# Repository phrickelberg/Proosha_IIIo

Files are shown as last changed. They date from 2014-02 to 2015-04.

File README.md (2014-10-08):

Proosha IIIo
=========================

This RepRap is available under GPL license.

This is basically a Prusa i3 Einstein Rework with minor changes such as:

* wood-style frame with fins upgraded to fit the Einstein Rework Y-CORNERS
* stronger X-END-IDLER
* stronger X-END-MOTOR
* preconfigured Marlin Firmware

Building instructions
-------------------------
Instead of the original threaded rod configuration, you need

* 2x Threaded rod M5x300 mm
* 2x Threaded rod M10x210 mm
* 2x Threaded rod M10x365 mm
* 2x Threaded rod M10x380 mm

and a few more M10 nuts and washers plus two M8 x 20 mm screws.

You also need to tap the printed X-END-IDLER-BETTER.stl twice with a M8 x 1,25 thread. Thats where the two M8 x 20 mm screws go.

Besides that, just follow the instructions from [the original project page](http://reprap.org/wiki/Prusa_i3_Rework_Introduction/de)

If you want to use the preconfigured Marlin Firmware, please make sure you got your hardware configured as followed:
* explanation:				{X-AXIS, Y-AXIS, Z-AXIS, EXTRUDER}
* microstepping:			{1/8, 1/8, 1/4, 1/4}
* motors step angle:	{1.8, 1.8, 1.8, 1.8}
* transmission:				{20 teeth GT2, 20 teeth GT2, M5 thread (0.8 mm/rev), hardened steel hobbed bolt + wade gear}

Roadmap
-------------------------

- [x] modifying the x-end idler to more solid, right now the ball-bearing mount it's a predetermined breaking point
- [x] modifying the wood frame fins to fit the i3 EINSTEIN Rework y-corners and 10mm threaded rods
- [ ] modifying the y-carrier for 3-point leveling AND for triggering the lower y-endstop even if the bed is mounted a few mm higher (i.e. due to leveling screws)

Sources
-------------------------

* Prusa i3 EINSTEIN Rework Introduction [github.com](http://reprap.org/wiki/Prusa_i3_Rework_Introduction)
* Extruder-Classic parts by ch1t0 [Thingiverse](http://www.thingiverse.com/thing:76660)
* Extruder-E3D parts by Mak-a-face [Thingiverse](http://www.thingiverse.com/thing:76660)
* Extruder parts by ch1t0 [Thingiverse](http://www.thingiverse.com/thing:76660)
* Marlin Firmware [GitHub](https://github.com/ErikZalm/Marlin)

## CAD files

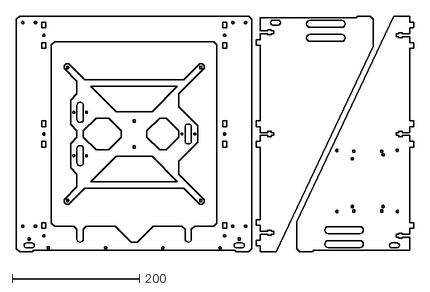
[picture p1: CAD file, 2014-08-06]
Frame/Prusa3WOOD-v4-Einstein-Rework-Retrofit-Laser-Closed-Radius-140722.dxf
623.9 x 370.0

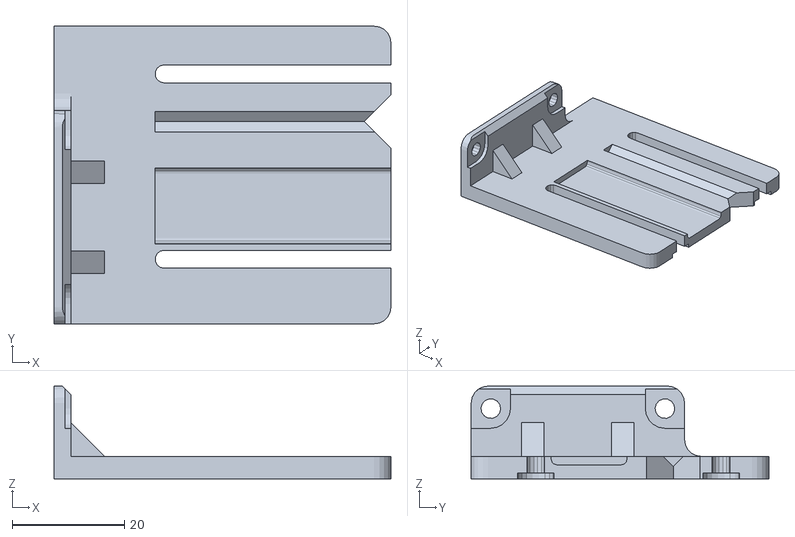
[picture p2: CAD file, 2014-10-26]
STL parts/ENSTOP-Z-HOLDER/ENDSTOP-Z-HOLDER-LONGER.stl
60.0 x 53.0 x 16.5

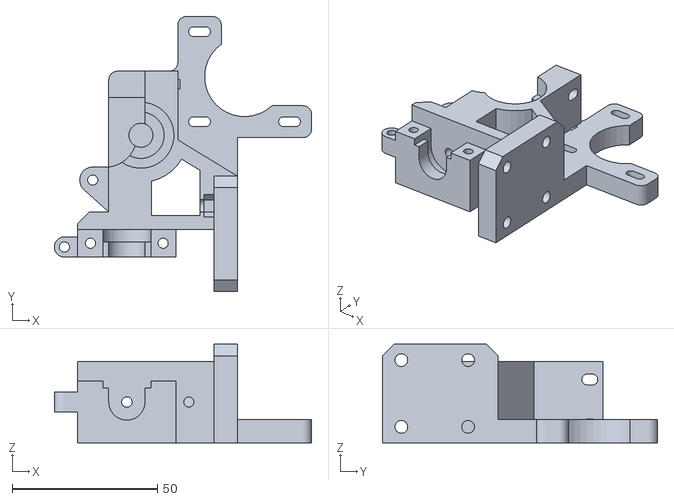
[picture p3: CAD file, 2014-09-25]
STL parts/EXTRUDEUR/BODY-EXTRUDER-WADE-E3D/i3R_E3D_Extruder_01.STL
88.7 x 94.7 x 34.0

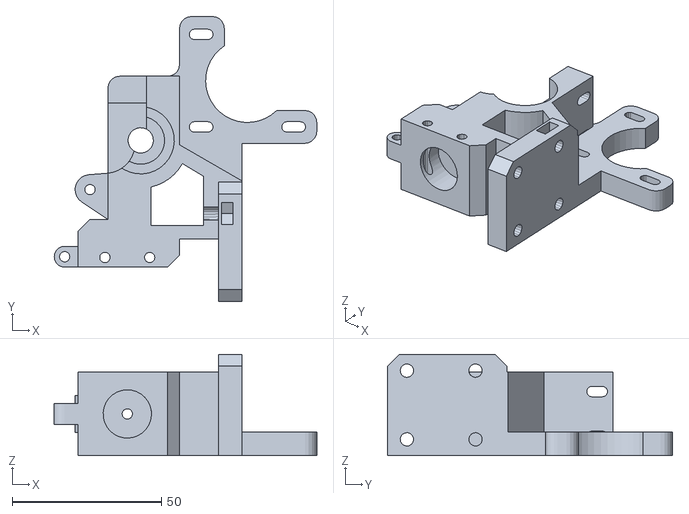
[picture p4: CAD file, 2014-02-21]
STL parts/EXTRUDEUR/BODY-EXTRUDEUR-WADE-CLASSIC/BODY-EXTRUDEUR-WADE.stl
88.0 x 95.5 x 34.0

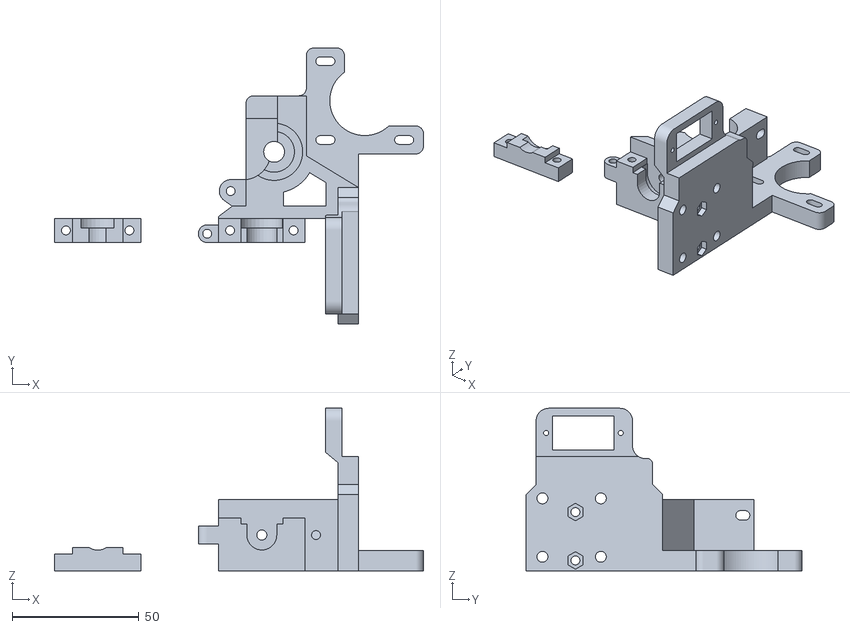
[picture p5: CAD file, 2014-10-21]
STL parts/EXTRUDEUR/BODY-EXTRUDEUR-WADE-E3D-AB/e3dv6_with_clip.stl
145.3 x 108.7 x 64.0

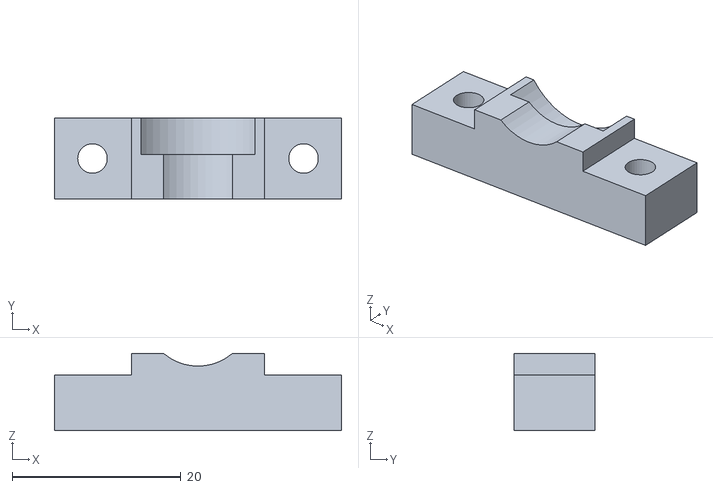
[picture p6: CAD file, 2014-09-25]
STL parts/EXTRUDEUR/BODY-EXTRUDEUR-WADE-E3D/i3R_E3D_Mounting_Clamp_01.STL
34.0 x 9.58 x 9.12

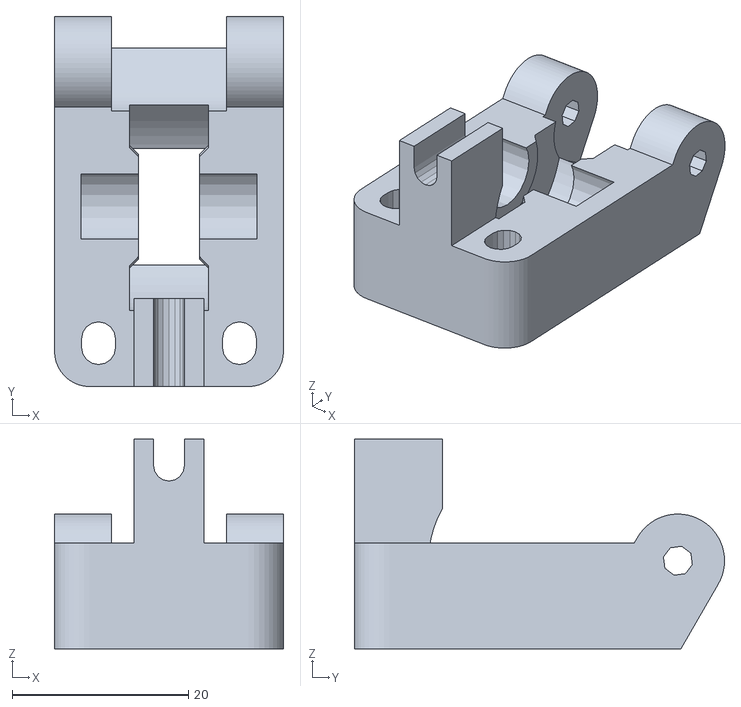
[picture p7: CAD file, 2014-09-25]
STL parts/EXTRUDEUR/EXTRUDER-IDLER/EXTRUDER-IDLER-avec-guide.stl
26.0 x 42.0 x 23.8

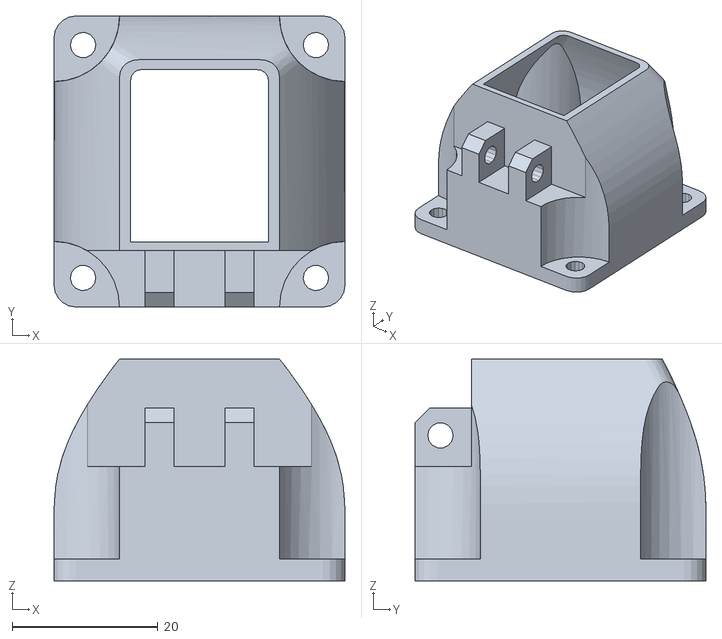
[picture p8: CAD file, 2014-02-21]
STL parts/EXTRUDEUR/FAN-DUCT/FAN-DUCT.stl
40.0 x 40.0 x 30.5

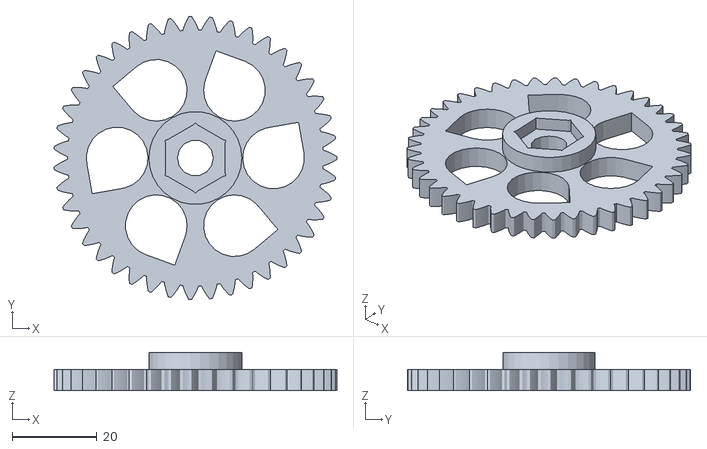
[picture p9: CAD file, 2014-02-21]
STL parts/EXTRUDEUR/WADE-BIG-GEAR/WADE-BIG-GEAR.stl
66.9 x 67.0 x 9.00

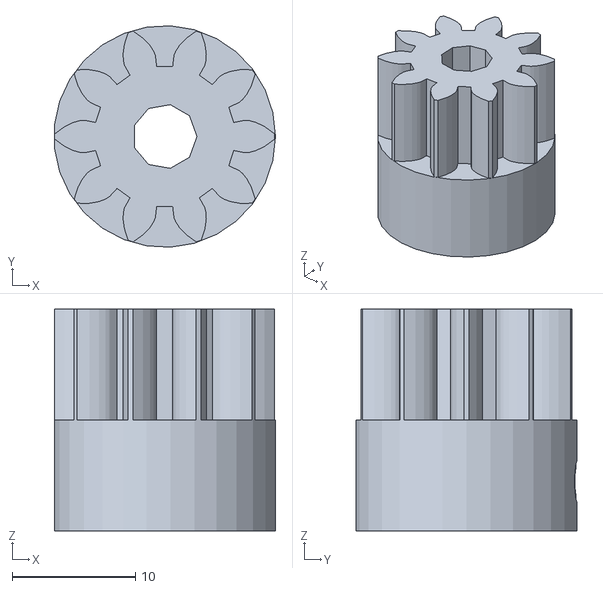
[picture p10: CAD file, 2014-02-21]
STL parts/EXTRUDEUR/WADE-SMALL-GEAR/WADE-SMALL-GEAR.stl
17.9 x 18.0 x 18.0

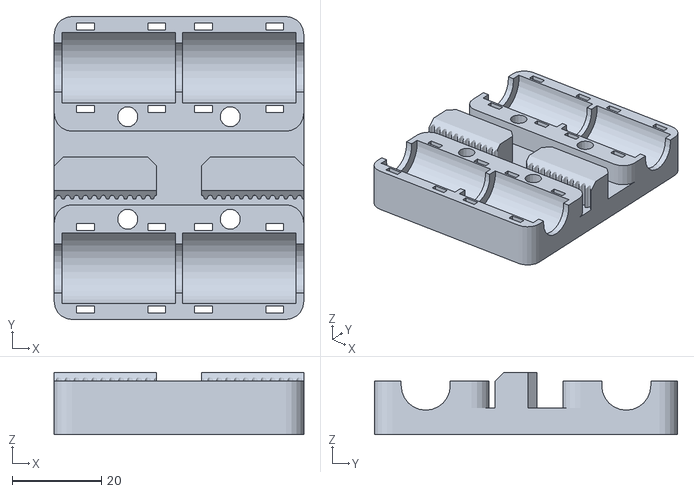
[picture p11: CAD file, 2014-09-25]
STL parts/X-CARRIAGE/X-CARRIAGE-IGUS.stl
56.0 x 68.0 x 14.0

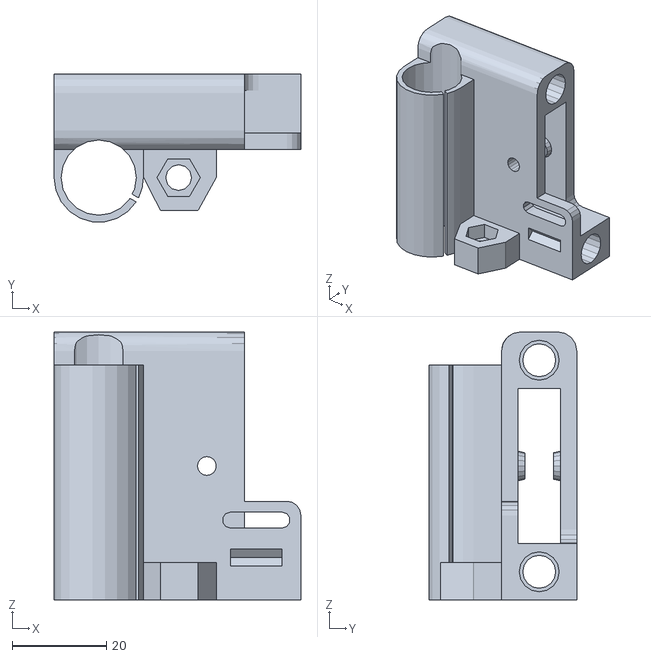
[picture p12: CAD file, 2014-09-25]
STL parts/X-END-IDLER/X-END-IDLER-BETTER-IGUS.stl
52.5 x 31.4 x 57.0

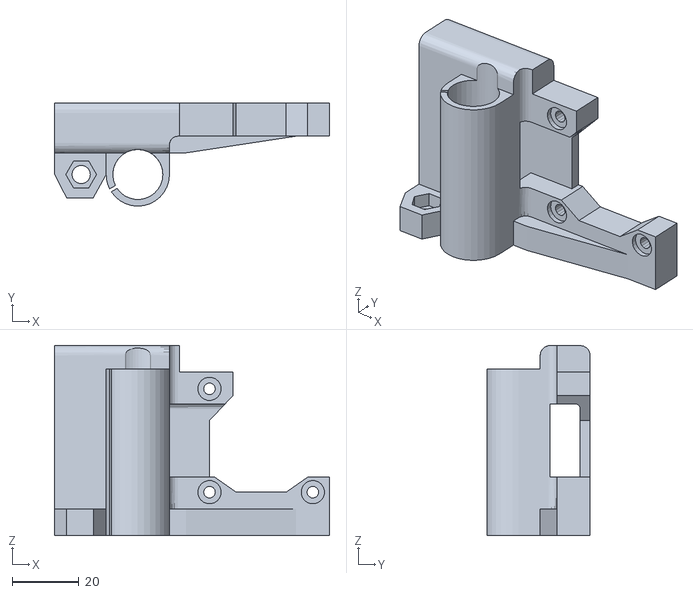
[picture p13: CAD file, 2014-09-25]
STL parts/X-END-MOTOR/X-END-MOTOR-V2.stl
82.5 x 31.0 x 57.0

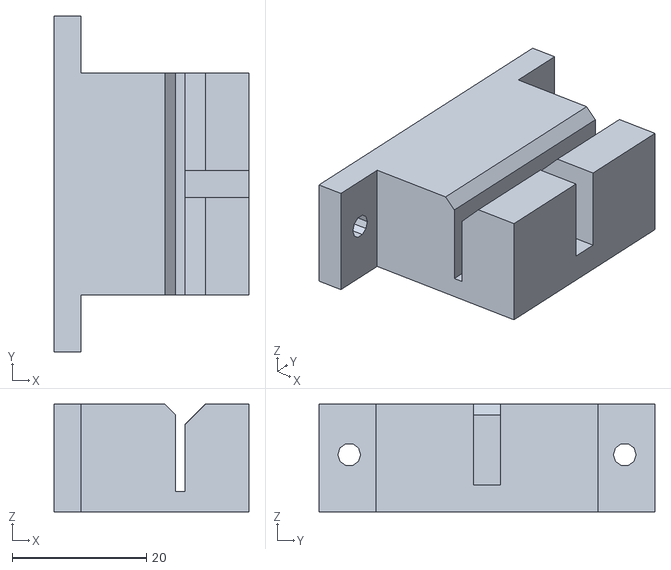
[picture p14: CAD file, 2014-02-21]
STL parts/Y-BELT-HOLDER/Y-BELT-HOLDER.stl
29.0 x 50.0 x 16.0

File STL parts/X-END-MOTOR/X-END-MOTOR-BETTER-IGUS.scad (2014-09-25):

module vanilla_motor(){
	import("X-END-MOTOR.stl");
}

motor_center=[44.75,2.5,0];
cutout_offset=8;

module better_motor(){
	difference(){
		union(){
			vanilla_motor();
			patch();
		}
		cutout();
	}
}

module patch(){
	union(){
		intersection(){
			translate([31.75,6,0])
				cube([10,3,32],center=true);
			translate([44.75,6,0])
				rotate([90,0,0])
					cylinder(r=20,h=3,center=true);
		}
		intersection(){
			union(){
				translate([34.5,2.5,13.25])
					cube([4.5,10,4.5],center=true);
				//translate([34.5,2.5,-13.25])
					//cube([4.5,10,4.5],center=true);
				translate([44.75,2.5,-15.5])
					cube([25,10,9],center=true);
		
			}
			translate([44.75,2.5,0])
				rotate([90,0,0])
					cylinder(r=18,h=10,center=true);
		}
	}
}

module cutout(){
	union(){
		translate([motor_center[0]-cutout_offset,2.5,motor_center[2]+cutout_offset])
			rotate([90,0,0])
				cylinder(r=6.5,h=11,center=true,$fn=36);
		translate([motor_center[0]-cutout_offset,2.5,motor_center[2]-cutout_offset])
			rotate([90,0,0])
				cylinder(r=6.5,h=11,center=true,$fn=36);
		translate([motor_center[0]+cutout_offset,2.5,motor_center[2]-cutout_offset])
			rotate([90,0,0])
				cylinder(r=6.5,h=11,center=true,$fn=36);
		translate([motor_center[0]-cutout_offset,2.5,0])
			cube([13,11,2*cutout_offset],center=true);
		translate([motor_center[0],2.5,motor_center[2]-cutout_offset])
			cube([2*cutout_offset,11,13],center=true);
		translate([motor_center[0]-cutout_offset,2.5,motor_center[2]+cutout_offset])
			rotate([90,0,0])
				cylinder(r=6.5,h=11,center=true,$fn=36);
		intersection(){
			translate([motor_center[0]-cutout_offset,2.5,motor_center[2]+cutout_offset])
				rotate([0,45,0])
					translate([0,0,6.5])
						cube([13,11,13],center=true,$fn=36);
			translate([motor_center[0]-cutout_offset,2.5,motor_center[2]+cutout_offset])
				rotate([0,45,0])
					cube([13,11,26],center=true,$fn=36);
			translate([motor_center[0]-cutout_offset,2.5,motor_center[2]+cutout_offset])
				cube([13,11,26],center=true,$fn=36);
		}
	}
}

module igus_motor(){
	difference(){
		better_motor();
		translate([7.75,-14,0])
			cylinder(r=16/2, h=60, center=true, $fn=20);
	}
}


igus_motor();

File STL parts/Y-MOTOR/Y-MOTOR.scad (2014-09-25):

projection(cut=true)
	translate([-50,0,-8])
		import("/Users/Moritz/Downloads/Proosha_IIIo-master/STL parts/Y-MOTOR/Y-MOTOR.stl");

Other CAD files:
STL parts/Y-CORNERS/experimental/Y-CORNERS.dxf
STL parts/Y-CORNERS/Y-CORNERS-HOLLOW.stl
STL parts/Y-IDLER/Y-IDLER.stl
STL parts/Y-MOTOR/Y-MOTOR.stl
STL parts/X-END-MOTOR/X-END-MOTOR-BETTER.scad
STL parts/X-END-MOTOR/X-END-MOTOR-IGUS.scad
Frame/Proosha_IIIo-Frame-v1.dxf
STL parts/ENSTOP-Z-HOLDER/ENDSTOP-Z-HOLDER-LONGER.scad
STL parts/ENSTOP-Z-HOLDER/ENDSTOP-Z-HOLDER.stl
STL parts/EXTRUDEUR/BODY-EXTRUDEUR-WADE-CLASSIC/BODY-EXTRUDEUR-WADE.scad
STL parts/EXTRUDEUR/BODY-EXTRUDEUR-WADE-E3D-AB/e3d_extru_alnoa_1.75_ab-only-clip.scad
STL parts/EXTRUDEUR/BODY-EXTRUDEUR-WADE-E3D-AB/e3d_extru_alnoa_1.75_ab-only-clip.stl
STL parts/EXTRUDEUR/BODY-EXTRUDEUR-WADE-E3D-AB/e3d_extru_alnoa_1.75_ab-without-clip.scad
STL parts/EXTRUDEUR/BODY-EXTRUDEUR-WADE-E3D-AB/e3d_extru_alnoa_1.75_ab-without-clip.stl
STL parts/EXTRUDEUR/BODY-EXTRUDEUR-WADE-E3D-AB/e3d_extru_alnoa_1.75_ab.STL
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

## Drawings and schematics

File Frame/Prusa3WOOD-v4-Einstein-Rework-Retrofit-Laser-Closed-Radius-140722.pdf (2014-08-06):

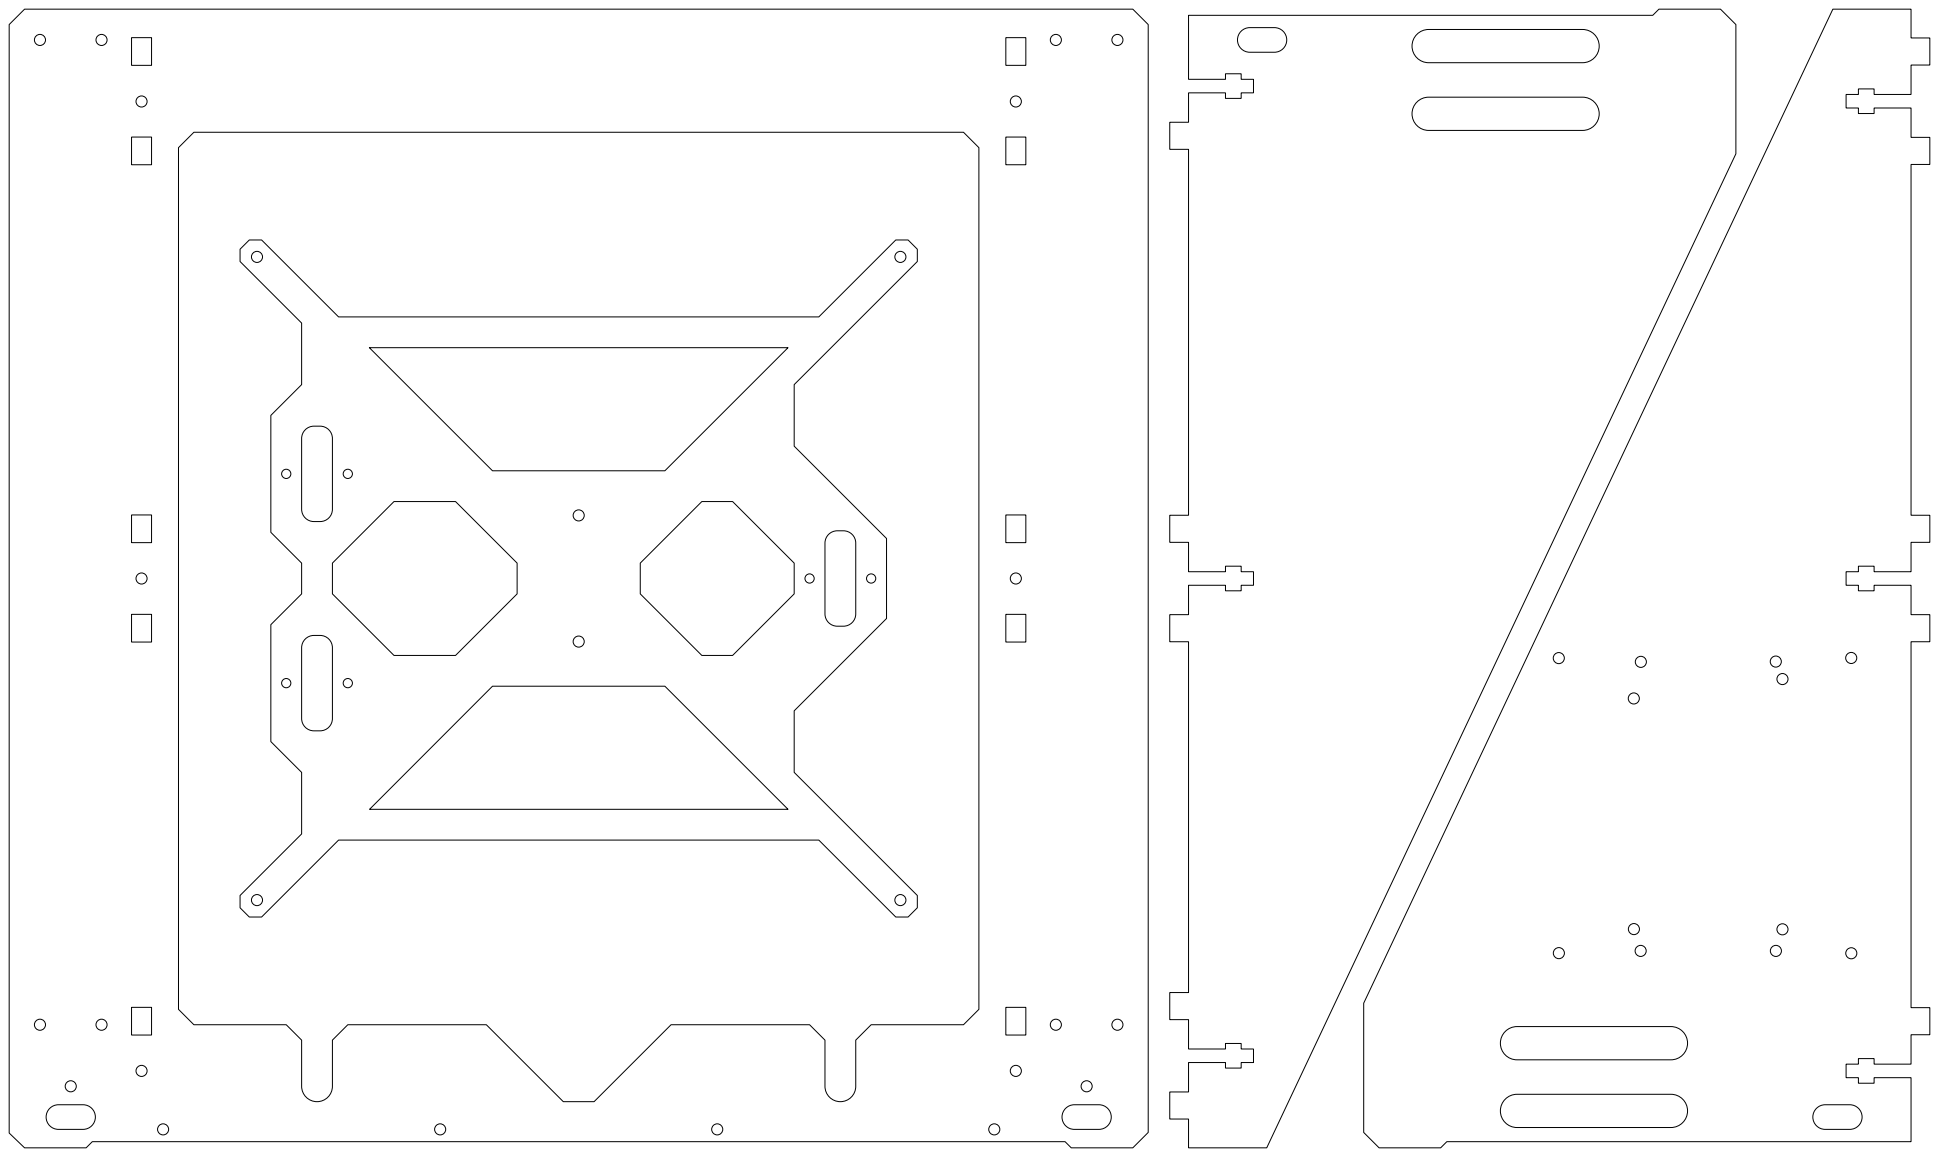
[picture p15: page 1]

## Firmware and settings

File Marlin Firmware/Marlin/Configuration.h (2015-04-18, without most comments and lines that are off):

#define CONFIGURATION_H
#define STRING_VERSION_CONFIG_H __DATE__ " " __TIME__ // build date and time
#define STRING_CONFIG_H_AUTHOR "(none, default config)" // Who made the changes.
#define SERIAL_PORT 0
#define BAUDRATE 250000
#define MOTHERBOARD 33
#define CUSTOM_MENDEL_NAME "> Totti <"
#define EXTRUDERS 1
#define POWER_SUPPLY 1
#define TEMP_SENSOR_0 5
#define TEMP_SENSOR_1 0
#define TEMP_SENSOR_2 0
#define TEMP_SENSOR_BED 5
#define MAX_REDUNDANT_TEMP_SENSOR_DIFF 10
#define TEMP_RESIDENCY_TIME 5  // (seconds)
#define TEMP_HYSTERESIS 2       // (degC) range of +/- temperatures considered "close" to the target one
#define TEMP_WINDOW     1       // (degC) Window around target to start the residency timer x degC early.
#define HEATER_0_MINTEMP 5
#define HEATER_1_MINTEMP 5
#define HEATER_2_MINTEMP 5
#define BED_MINTEMP 5
#define HEATER_0_MAXTEMP 315
#define HEATER_1_MAXTEMP 315
#define HEATER_2_MAXTEMP 315
#define BED_MAXTEMP 165
#define PIDTEMP
#define BANG_MAX 255 // limits current to nozzle while in bang-bang mode; 255=full current
#define PID_MAX 255 // limits current to nozzle while PID is active (see PID_FUNCTIONAL_RANGE below); 255=full current
  #define PID_FUNCTIONAL_RANGE 10 // If the temperature difference between the target temperature and the actual temperature
  #define PID_INTEGRAL_DRIVE_MAX 255  //limit for the integral term
  #define K1 0.95 //smoothing factor within the PID
  #define PID_dT ((OVERSAMPLENR * 8.0)/(F_CPU / 64.0 / 256.0)) //sampling period of the temperature routine
#define  DEFAULT_Kp 53.50
#define  DEFAULT_Ki 9.38
#define  DEFAULT_Kd 76.26
#define PIDTEMPBED
#define MAX_BED_POWER 255 // limits duty cycle to bed; 255=full current
    #define  DEFAULT_bedKp 46.34
    #define  DEFAULT_bedKi 4.23
    #define  DEFAULT_bedKd 126.8
#define PREVENT_DANGEROUS_EXTRUDE
#define PREVENT_LENGTHY_EXTRUDE
#define EXTRUDE_MINTEMP 170
#define EXTRUDE_MAXLENGTH (X_MAX_LENGTH+Y_MAX_LENGTH) //prevent extrusion of very large distances.
#define THERMAL_RUNAWAY_PROTECTION_PERIOD 40 //in seconds
#define THERMAL_RUNAWAY_PROTECTION_HYSTERESIS 4 // in degree Celsius
#define THERMAL_RUNAWAY_PROTECTION_BED_PERIOD 20 //in seconds
#define THERMAL_RUNAWAY_PROTECTION_BED_HYSTERESIS 4 // in degree Celsius
const bool X_MIN_ENDSTOP_INVERTING = true; // set to true to invert the logic of the endstop.
const bool Y_MIN_ENDSTOP_INVERTING = true; // set to true to invert the logic of the endstop.
const bool Z_MIN_ENDSTOP_INVERTING = true; // set to true to invert the logic of the endstop.
const bool X_MAX_ENDSTOP_INVERTING = true; // set to true to invert the logic of the endstop.
const bool Y_MAX_ENDSTOP_INVERTING = true; // set to true to invert the logic of the endstop.
const bool Z_MAX_ENDSTOP_INVERTING = true; // set to true to invert the logic of the endstop.
#if defined(COREXY) && !defined(DISABLE_MAX_ENDSTOPS)
  #define DISABLE_MAX_ENDSTOPS
#endif
#define X_ENABLE_ON 0
#define Y_ENABLE_ON 0
#define Z_ENABLE_ON 0
#define E_ENABLE_ON 0 // For all extruders
#define DISABLE_X false
#define DISABLE_Y false
#define DISABLE_Z false
#define DISABLE_E false // For all extruders
#define DISABLE_INACTIVE_EXTRUDER true //disable only inactive extruders and keep active extruder enabled
#define INVERT_X_DIR false    // for Mendel set to false, for Orca set to true
#define INVERT_Y_DIR true    // for Mendel set to true, for Orca set to false
#define INVERT_Z_DIR false     // for Mendel set to false, for Orca set to true
#define INVERT_E0_DIR true   // for direct drive extruder v9 set to true, for geared extruder set to false
#define INVERT_E1_DIR false    // for direct drive extruder v9 set to true, for geared extruder set to false
#define INVERT_E2_DIR false   // for direct drive extruder v9 set to true, for geared extruder set to false
#define X_HOME_DIR 1
#define Y_HOME_DIR -1
#define Z_HOME_DIR -1
#define min_software_endstops true // If true, axis won't move to coordinates less than HOME_POS.
#define max_software_endstops true  // If true, axis won't move to coordinates greater than the defined lengths below.
#define X_MAX_POS 200
#define X_MIN_POS 0
#define Y_MAX_POS 170
#define Y_MIN_POS 0
#define Z_MAX_POS 180
#define Z_MIN_POS 0
#define X_MAX_LENGTH (X_MAX_POS - X_MIN_POS)
#define Y_MAX_LENGTH (Y_MAX_POS - Y_MIN_POS)
#define Z_MAX_LENGTH (Z_MAX_POS - Z_MIN_POS)
#define Z_PROBE_REPEATABILITY_TEST  // If not commented out, Z-Probe Repeatability test will be included if Auto Bed Leveling is Enabled.
#define MANUAL_X_HOME_POS 200
#define MANUAL_Y_HOME_POS 0
#define MANUAL_Z_HOME_POS 0
#define NUM_AXIS 4 // The axis order in all axis related arrays is X, Y, Z, E
#define HOMING_FEEDRATE {50*60, 50*60, 3*60, 0}  // set the homing speeds (mm/min)
#define DEFAULT_AXIS_STEPS_PER_UNIT   {100,100,4000,680}
#define DEFAULT_MAX_FEEDRATE          {500, 500, 3, 25}    // (mm/sec)
#define DEFAULT_MAX_ACCELERATION      {9000,9000,100,10000}    // X, Y, Z, E maximum start speed for accelerated moves. E default values are good for Skeinforge 40+, for older versions raise them a lot.
#define DEFAULT_ACCELERATION          2000    // X, Y, Z and E max acceleration in mm/s^2 for printing moves
#define DEFAULT_RETRACT_ACCELERATION  3000   // X, Y, Z and E max acceleration in mm/s^2 for retracts
#define DEFAULT_XYJERK                20.0    // (mm/sec)
#define DEFAULT_ZJERK                 0.4     // (mm/sec)
#define DEFAULT_EJERK                 5.0    // (mm/sec)
#define CUSTOM_M_CODES
  #define CUSTOM_M_CODE_SET_Z_PROBE_OFFSET 851
  #define Z_PROBE_OFFSET_RANGE_MIN -15
  #define Z_PROBE_OFFSET_RANGE_MAX -5
#define EEPROM_SETTINGS
#define EEPROM_CHITCHAT
#define PLA_PREHEAT_HOTEND_TEMP 255
#define PLA_PREHEAT_HPB_TEMP 90
#define PLA_PREHEAT_FAN_SPEED 255   // Insert Value between 0 and 255
#define ABS_PREHEAT_HOTEND_TEMP 255
#define ABS_PREHEAT_HPB_TEMP 102 //110
#define ABS_PREHEAT_FAN_SPEED 255   // Insert Value between 0 and 255
#define ENCODER_PULSES_PER_STEP 1 // Increase if you have a high resolution encoder
#define ENCODER_STEPS_PER_MENU_ITEM 5 // Set according to ENCODER_PULSES_PER_STEP or your liking
#define REPRAP_DISCOUNT_SMART_CONTROLLER
#define REPRAP_DISCOUNT_FULL_GRAPHIC_SMART_CONTROLLER
 #define DOGLCD
 #define U8GLIB_ST7920
 #define REPRAP_DISCOUNT_SMART_CONTROLLER
 #define ULTIPANEL
 #define NEWPANEL
  #define SDSUPPORT
  #define ULTRA_LCD
    #define LCD_WIDTH 20
    #define LCD_HEIGHT 5
#  define DEFAULT_LCD_CONTRAST 32
#define SOFT_PWM_SCALE 0
#include "Configuration_adv.h"
#include "thermistortables.h"

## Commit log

2014-02-21 fork cleanup
    [PLATEAU_1_i3_POUR_PRUSA.stl, PLATEAU_1_i3_POUR_UP.stl, PLATEAU_2_i3_POUR_UP.stl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]
2014-02-21 fork translation, added more solid x idlers
    [ARDUINO-WASHER.stl, BODY-EXTRUDEUR-WADE.stl, ENDSTOP-Z-HOLDER.stl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]
2014-02-22 intial commit for frame
    this frame is rework compatible and allows 3-point leveling
    [Proosha_IIIo-Frame-v1.dxf]
2014-05-06 updated frame, cleanup
    build is now in useable state
    [Prusa3WOOD-v4-Einstein-Rework-Retrofit.dxf, X-END-IDLER-STRONGER.scad, X-END-IDLER-STRONGER.stl]
2014-07-18 several improvements
    improved x-end-idler design, fixed design flaws in the frame layout
    [Prusa3WOOD-v4-Einstein-Rework-Retrofit-Laser-Closed-140708.dxf, Prusa3WOOD-v4-Einstein-Rework-Retrofit.dxf, X-END-IDLER-BETTER.scad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]
2014-08-06 frame improvements
    cleanup, replaced polygons with curves
    [Prusa3WOOD-v4-Einstein-Rework-Retrofit-Laser-Closed-140708.dxf, Prusa3WOOD-v4-Einstein-Rework-Retrofit-Laser-Closed-Radius-140722.dxf]
2014-09-25 mighty update
    [BODY-EXTRUDEUR-WADE.scad, BODY-EXTRUDEUR-WADE.stl, EXTRUDER-IDLER-avec-guide-BOWDEN.scad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]
2014-10-08 added preconfigured Marlin firmware
    [Configuration.h, Configuration_adv.h, Menu Plans.xlsx]
2014-10-21 added e3dv6 version of extruder body with servo attachment
    [e3dv6_with_clip.scad, e3dv6_with_clip.stl]
2014-10-24 work in progress commit on parametrizing the stls
    [X-END-IDLER-RE.scad, Y-CORNERS-4-ESTLCAM.dxf, Y-CORNERS-HOLLOW-V2.stl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]
2014-10-26 Added longer, E3Dv6-ready z-endstop holder
    Added longer, E3Dv6-ready z-endstop holder with parameterized length.
    [ENDSTOP-Z-HOLDER-LONGER.scad, ENDSTOP-Z-HOLDER-LONGER.stl]
2015-02-05 Configed and Tuned
    [Configuration.h]
2015-04-18 menu order patched
    [Configuration.h]
